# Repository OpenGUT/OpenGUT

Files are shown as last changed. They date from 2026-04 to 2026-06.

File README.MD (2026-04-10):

# OpenGut: An Open-Source Platform for Gut–Computer Interaction Research

OpenGut is an open-source platform designed to enable research at the intersection of human-computer interaction (HCI), physiology, and interoception. It provides a complete end-to-end system for sensing, analyzing, and interacting with gut activity through a wearable device, software interface, and extensible documentation.

## 🚀 Motivation
The gut plays a critical role in human physiology and cognition through the gut–brain axis. Despite growing interest in gut-based interaction, existing tools are fragmented, application-specific, and lack accessibility. OpenGut addresses this gap by providing a unified, reproducible, and extensible platform for researchers and developers.

## 🧩 System Overview
OpenGut consists of three main components:

### 1. Wearable Hardware
- Custom PCB based on Nordic nRF52840
- Dual-microphone setup (body-facing + ambient) for gut sound capture
- MicroSD storage for long-term recording
- Plug-and-play support for audio and haptic actuators
- Designed as a belt-worn system for continuous, real-world use

### 2. Software Interface (GUI)
- Real-time audio visualization (waveforms + spectrograms)
- Annotation tools for gut signal analysis
- Noise suppression and filtering pipelines
- Configurable recording and playback parameters

### 3. Documentation & Open Resources
- Hardware design files (PCB, enclosure)
- Firmware and software codebase
- Step-by-step setup and usage guides
- Modular design for easy customization and extension

## ⚙️ Supported Modes
OpenGut supports multiple modes of operation:

- **Logger Mode**: Long-term gut sound recording
- **Playback Mode**: Audio/haptic rendering of gut signals
- **Real-time Loopback Mode**: Live sensing and feedback

## 📊 Validation
OpenGut has been technically evaluated for:
- Signal quality (high correlation with medical-grade stethoscopes)
- Longitudinal gut activity tracking
- 24-hour recording capability with low power consumption

## 💡 Applications
- Interoception research and bodily awareness
- Mental and emotional state sensing
- Health monitoring and digestion studies
- Interactive media and immersive experiences
- Biofeedback and wearable computing

## 🔓 Open Source Vision
OpenGut aims to lower the barrier to entry in gut-computer interaction research by providing a fully open, reproducible, and extensible platform for the community.

## 🤝 Contributions
We welcome contributions from researchers, engineers, and designers interested in advancing gut-based interaction systems.

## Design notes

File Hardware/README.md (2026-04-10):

## PCB Design & Flashing Guide

<p align="center">
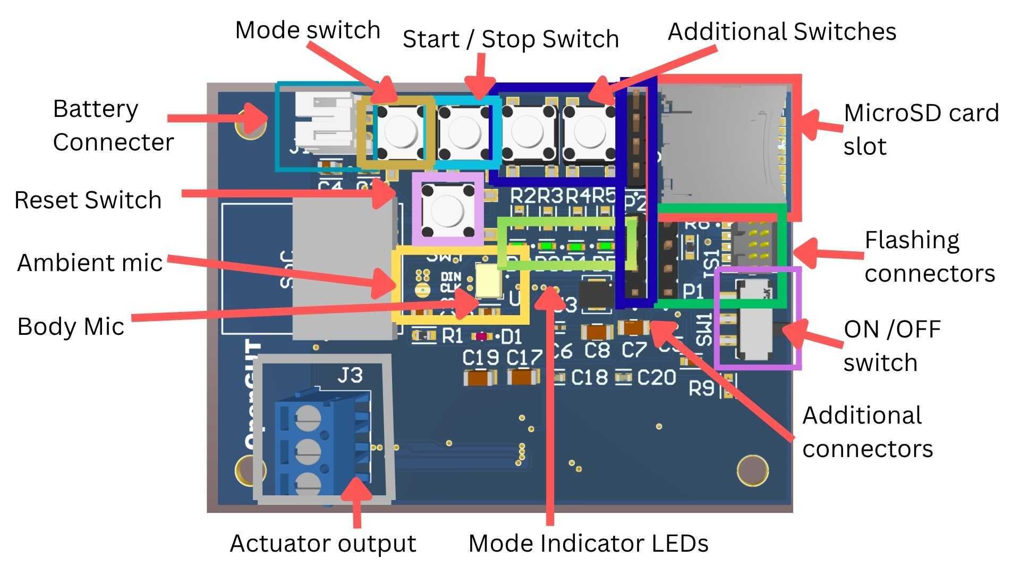
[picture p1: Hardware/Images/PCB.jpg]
  
</p>

The `Project_Output_OpenGUT.zip` file contains the Gerber files required for PCB manufacturing (e.g., via JLCPCB).

To modify the design, open the project file `OpenGUT.PrjPcb` in Altium Designer and make the necessary changes.

---

## Enclosure Design & Assembly Guide

### Overview
The enclosure consists of three 3D-printable components that house the electronics and provide a skin interface.

---

### Components

**Top Casing** – Protective upper shell  
<p align="center">
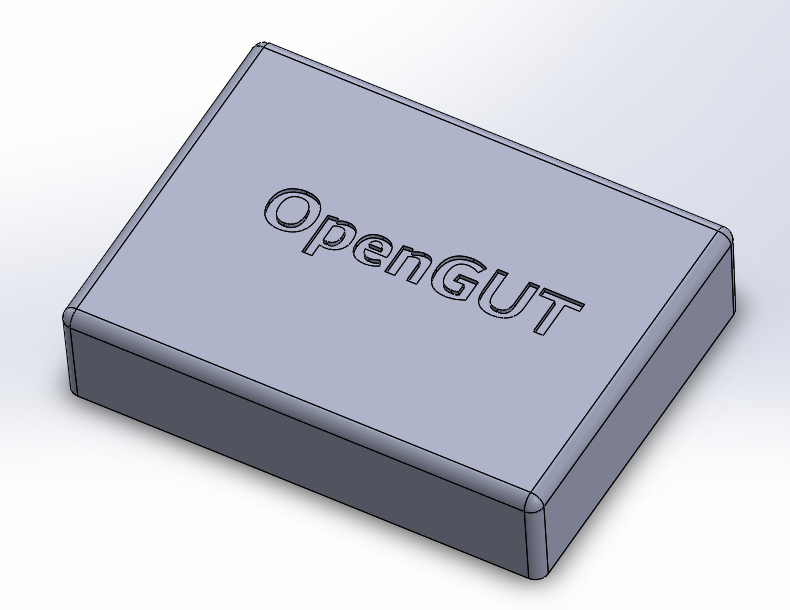
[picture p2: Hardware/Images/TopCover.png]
  
</p>

**Bottom Casing** – Structural base for internal components  
<p align="center">
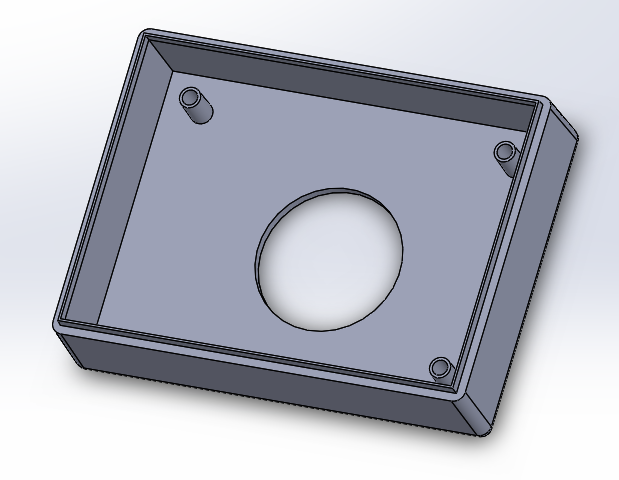
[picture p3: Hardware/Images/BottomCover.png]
  
</p>

**Conical Interface** – Skin-contact interface  
<p align="center">
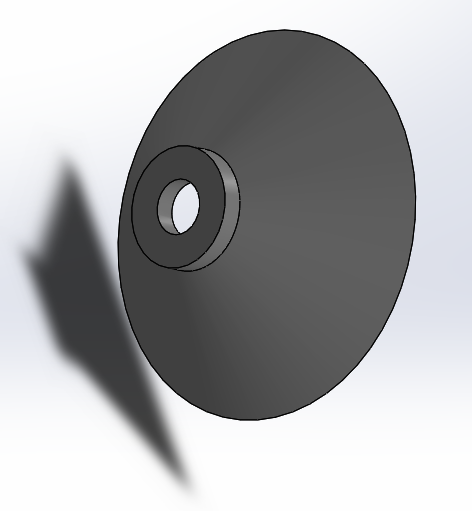
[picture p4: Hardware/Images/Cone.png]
  
</p>

---

## Assembly Instructions

### 1. Diaphragm Attachment
Attach a standard Littmann diaphragm directly to the cone.  
[Example Littmann diaphragm][littmann]

<p align="center">
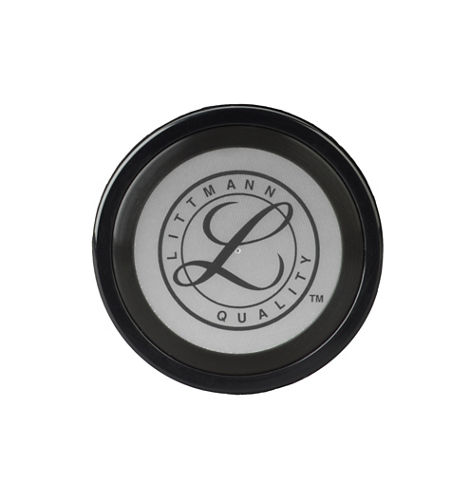
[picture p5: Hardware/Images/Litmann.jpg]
  
</p>

---

### 2. PCB & Casing Integration
- Screw the PCB into the mounting points on the bottom casing  
- Secure the cone to the bottom casing using hot glue  

<p align="center">
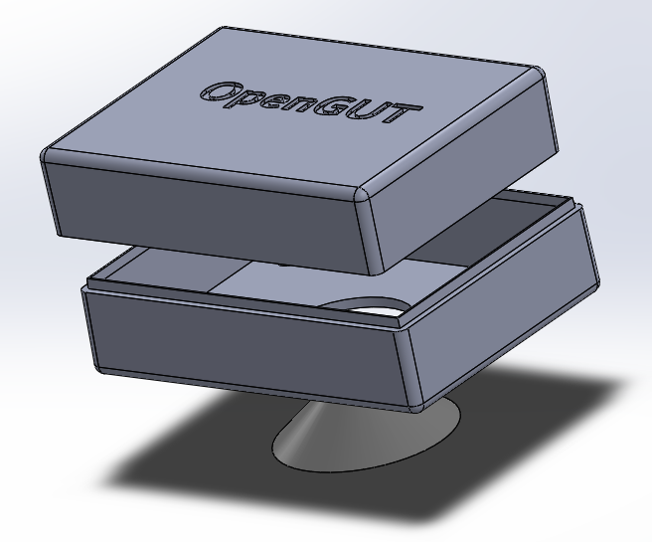
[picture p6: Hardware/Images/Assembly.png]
  
</p>

- Attach the top casing using the lip-and-groove mechanism  

---

### 3. Final Inspection
Ensure all components are securely fitted and properly aligned before use.

---

[littmann]: https://www.ebay.com/itm/366332360002

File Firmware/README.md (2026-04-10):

## Firmware Options

We provide two firmware versions depending on the researcher’s preferred workflow.

---

### 1. Firmware_UI_based_Selection

This firmware wraps all settings into the UI.

#### Setup & Flashing
- Set up the Zephyr / NCS environment  
  - Recommended: nRF Connect SDK on VS Code  
- Build the firmware  
- Flash using an nRF52840 DK  
  - Connect **Debug Out (DK)** → **Debug In (PCB)**  
- Flash the firmware onto the PCB  

Once flashed, the PCB is ready to use.

#### Usage
1. Insert the SD card into your laptop  
2. Using the provided UI, select:
   - Mode  
   - Sampling rate  
   - Duration  
   - File name  
3. Remove the SD card and insert it into the PCB  
4. Turn ON the PCB  

→ The selected mode will run automatically  

---

### 2. Firmware_Button_based_Selection

This firmware keeps primary settings (sampling rate, file name, etc.) in the UI,  
but allows mode control directly on the PCB using buttons.

#### Setup
- Same flashing process as above  
- Configure settings using the UI  

#### Usage
Once powered ON:

- **Button 1** → Select mode  
  - Current mode is indicated by LEDs:
    - **LED1** → Stereo recording  
    - **LED2** → Loopback  
    - **LED3** → Playback (File A)  
    - **LED4** → Playback (File B)  

- **Button 2** → Start / Stop  

---

### Why Use Button-Based Firmware?

This firmware allows researchers to:
- Quickly switch between modes  
- Avoid removing the SD card repeatedly  
- Test different configurations on the go

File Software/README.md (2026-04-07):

# OpenGUT Software - Device Configuration / Sound Processing / Annotation / File Export

A Qt6-based Python GUI application for OpenGUT project. Originally developed by OpenGUT engineering team.
- Preview and annotate audio files with interactive waveform and spectrogram visualization.

## Features

- **OpenGUT Device Configuration**: Simple GUI to configure an OpenGUT hardware and export settings in JSON format
- **Audio Visualization**: Interactive waveform and spectrogram displays for L/R channels using librosa and pyqtgraph
- **Audio Processing (Filtering)**: Audio processing - filtering input audio with 1) high-pass filter implemented with SciPy package, or 2) [AudioSep](https://github.com/ryohajika/AudioSep) ML-based engine using natural language
- **Annotation System**: Create, edit, and manage annotations with:
  - Annotation name
  - Start and stop time markers
  - Comments
  - Export annotated segments as WAVE files

## Installation

0. Install Python 3.12.13
```bash
# if you're on macOS, Homebrew and Pyenv are installed
pyenv install 3.12.13
# you may want to setup a virtualenv
```

1. Clone this project
```bash
git clone https://github.com/OpenGUT/OpenGUT
cd OpenGUT/Software
git submodule init && git submodule update
```

2. Install dependencies:
```bash
pip install -r requirements_pyenv3.12.13_venv.txt
```

3. Run the application:
```bash
python main.py
```

## Data Collection Usage

1. Prepare a microSD card for the OpenGUT PCB board
2. On the GUI, go to "Device Config" tab to export `config.json` file and download it to the microSD card
3. Load the microSD card on the PCB board and do data sampling

## Post Processing Usage

1. **Load Audio**: Use the file browser on the left to navigate and select a WAVE file
2. **Visualize**: The center pane shows the audio waveform or spectrogram (toggle with dropdown)
3. **Annotate**: Use the right pane to:
   - Enter annotation details (name, timing, comments)
   - Click "Add Annotation" to create new annotations
   - Select annotations from the list to edit or delete
   - Click "Export Segment" to save annotated sections as new WAVE files

#### Details are available from OpenGUT Official Documentation page: https://opengut.github.io

## Project Structure

```
.
├── app_settings.py                           # Application settings script
├── app_settings.json                         # JSON settings file that will be loaded/updated whenever we run this software **(if missing it will be generated automatically)**
├── const.py                                  # Constant values definition, mostly UI components labeling
├── main.py                                   # Application entry point
├── requirements_pyenv3.12.13_venv.txt        # Python dependencies including those libraries we need to run AudioSep
├── requirements.txt                          # Python dependencies
├── ui/
│   ├── __init__.py
│   ├── main_window.py      # Main window layout
│   ├── file_browser.py     # File tree widget
│   ├── audio_viewer.py     # Visualization widget
│   └── annotation_panel.py # Annotation controls
├── filters
│   ├── __init__.py
│   ├── template_filter.py  # Base filter script (user custom template)
│   ├── filter_loader.py    # Simple script that look up and load filters available
│   ├── scipy_highpass_filter.py              # Butterworth filter implemented with SciPy
│   ├── audiosep_filter.py  # Experimental filter with AudioSep library (No batch processing, experimental)
│   └── audiosep_filter2.py # Experimental filter with AudioSep library (batch processing enabled, experimental)
└── README.md               # This README
```

## Requirements
Refer `requirements_pyenv3.12.13_venv.txt` for the details.
This software has been built and tested on macOS26, Python 3.12.13. Also,

- PyQt6==6.6.1
- librosa==0.10.0
- pyqtgraph==0.13.7
- numpy==1.24.3
- scipy==1.11.4
- soundfile==0.12.1

For the AudioSep filtering, we also used

- tokenizers>=0.14.0,<0.15
- transformers==4.34.0
- torch==2.10.0
- gradio==3.47.1

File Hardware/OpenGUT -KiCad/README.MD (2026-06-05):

# OpenGUT – KiCad PCB Design

This repository contains KiCad design files for the **OpenGUT** hardware platform.  
It extends the original OpenGUT repository by providing open-source PCB layouts and schematics created in KiCad.

---

## ✨ Contribution Highlights
- **KiCad PCB Design Files**: Complete board design using KiCad, ensuring accessibility and reproducibility in an open-source EDA toolchain.
- **IMU Integration**: Added an Inertial Measurement Unit (IMU) to support **noise cancellation** and enhanced sensing capabilities.
- **Open-Source Alignment**: Since OpenGUT is an open-source platform, developing its PCB in KiCad strengthens transparency, collaboration, and community-driven improvements.

---

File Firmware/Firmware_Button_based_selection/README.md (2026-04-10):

# Firmware UI Based Selection

- Use this firmware if you want to select modes using the buttons on the PCB. 

## Project Structure

- `src/` - Application source files
- `boards/` - Board overlay files
- `prj.conf` - Zephyr project configuration
- `CMakeLists.txt` - Build configuration

## Quick Start

1. Configure your Zephyr/NCS environment.
2. Build the project from the workspace root:
   ```bash
   west build -b nrf54l15dk_nrf54l15_cpuapp
   ```
3. Flash to the board:
   ```bash
   west flash
   ```

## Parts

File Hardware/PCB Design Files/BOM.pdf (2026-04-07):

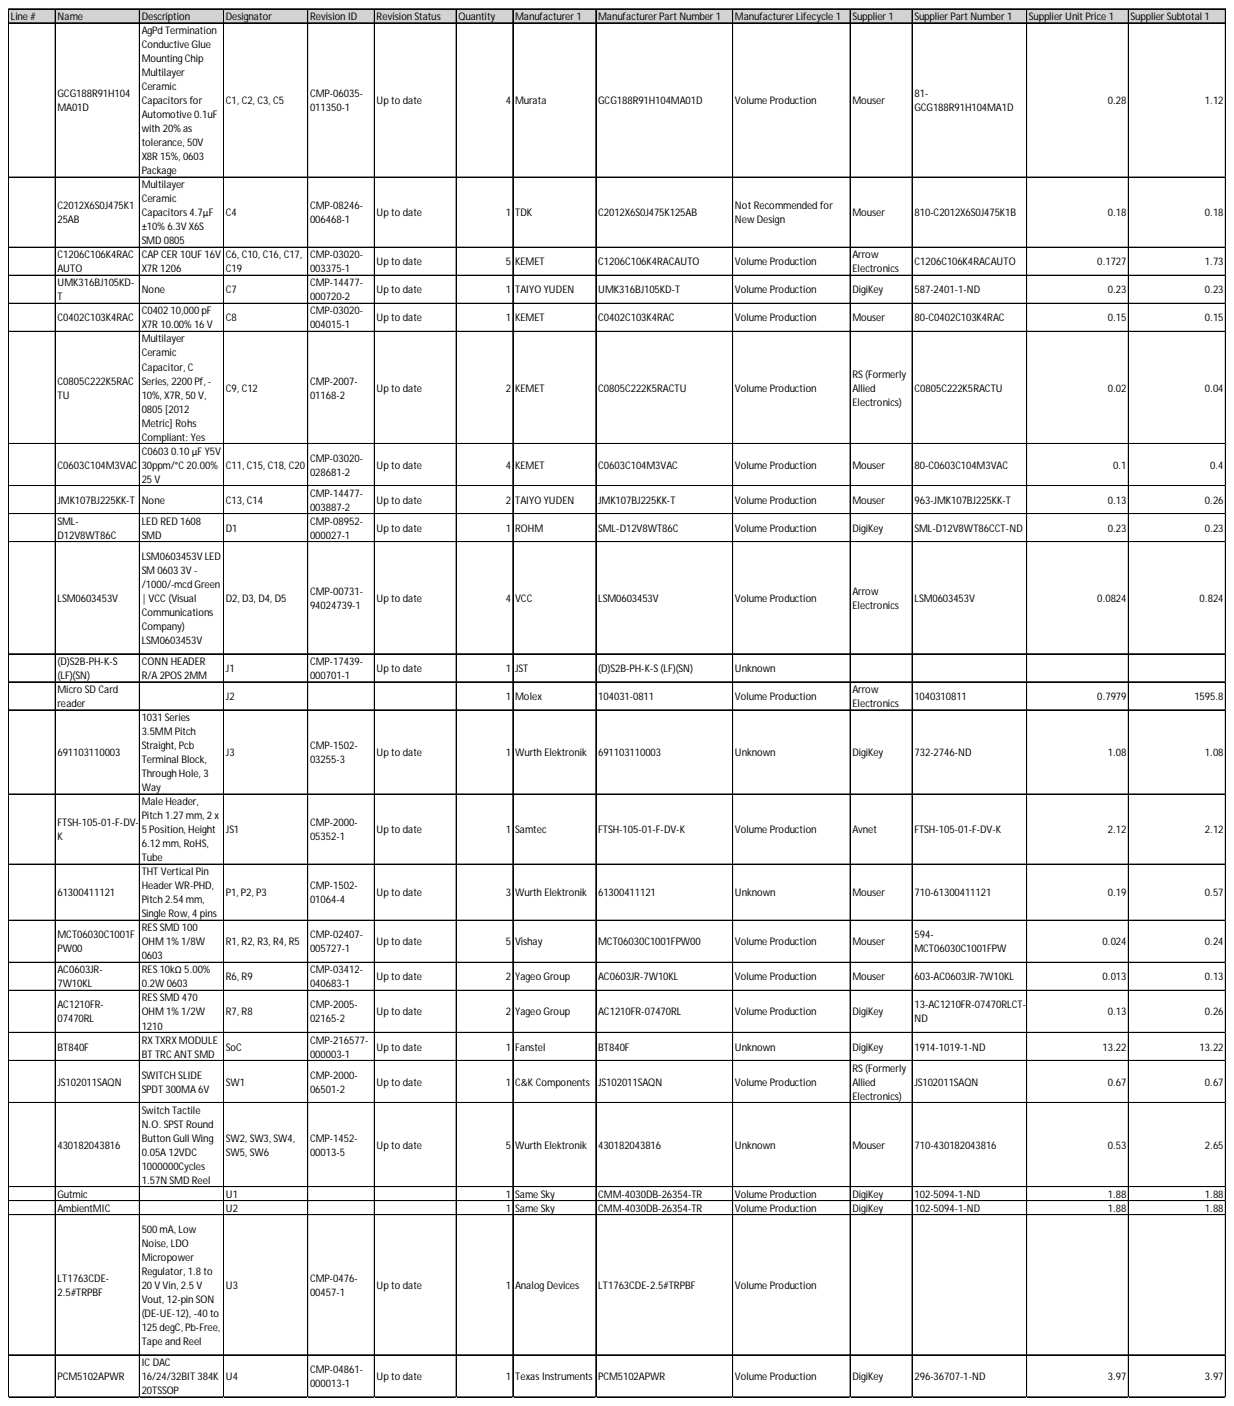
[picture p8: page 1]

Line # | Name | Description | Designator | Revision ID | Revision Status | Quantity | Manufacturer 1 | Manufacturer Part Number 1 | Manufacturer Lifecycle 1 | Supplier 1 | Supplier Part Number 1 | Supplier Unit Price 1 | Supplier Subtotal 1

GCG188R91H104 MA01D | AgPd Termination Conductive Glue Mounting Chip Multilayer Ceramic Capacitors for Automotive 0.1uF with 20% as tolerance, 50V X8R 15%, 0603 Package | C1, C2, C3, C5 | CMP-06035-011350-1 | Up to date | 4 Murata | | GCG188R91H104MA01D | Volume Production | Mouser | 81-GCG188R91H104MA1D | 0.28 | 1.12

C2012X6S0J475K1 25AB | Multilayer Ceramic Capacitors 4.7μF ±10% 6.3V X6S SMD 0805 | C4 | CMP-08246-006468-1 | Up to date | 1 | TDK | C2012X6S0J475K125AB | Not Recommended for New Design | Mouser | 810-C2012X6S0J475K1B | 0.18 | 0.18

C1206C106K4RAC AUTO | CAP CER 10UF 16V X7R 1206 | C6, C10, C16, C17, C19 | CMP-03020-003375-1 | Up to date | 5 | KEMET | C1206C106K4RACAUTO | Volume Production | Arrow Electronics | C1206C106K4RACAUTO | 0.1727 | 1.73

UMK316BJ105KD-T | None | C7 | CMP-14477-000720-2 | Up to date | 1 | TAIYO YUDEN | UMK316BJ105KD-T | Volume Production | DigiKey | 587-2401-1-ND | 0.23 | 0.23

C0402C103K4RAC | C0402 10,000 pF X7R 10.00% 16 V | C8 | CMP-03020-004015-1 | Up to date | 1 | KEMET | C0402C103K4RAC | Volume Production | Mouser | 80-C0402C103K4RAC | 0.15 | 0.15

C0805C222K5RAC TU | Multilayer Ceramic Capacitor, C Series, 2200 Pf, -10%, X7R, 50 V, 0805 [2012 Metric] Rohs Compliant: Yes | C9, C12 | CMP-2007-01168-2 | Up to date | 2 | KEMET | C0805C222K5RACTU | Volume Production | RS (Formerly Allied Electronics) | C0805C222K5RACTU | 0.02 | 0.04

C0603C104M3VAC | C0603 0.10 μF Y5V 30ppm/°C 20.00% 25 V | C11, C15, C18, C20 | CMP-03020-028681-2 | Up to date | 4 KEMET | | C0603C104M3VAC | Volume Production | Mouser | 80-C0603C104M3VAC | 0.1 | 0.4

JMK107BJ225KK-T | None | C13, C14 | CMP-14477-003887-2 | Up to date | 2 | TAIYO YUDEN | JMK107BJ225KK-T | Volume Production | Mouser | 963-JMK107BJ225KK-T | 0.13 | 0.26

SML-D12V8WT86C | LED RED 1608 SMD | D1 | CMP-08952-000027-1 | Up to date | 1 | ROHM | SML-D12V8WT86C | Volume Production | DigiKey | SML-D12V8WT86CCT-ND | 0.23 | 0.23

LSM0603453V | LSM0603453V LED SM 0603 3V -/1000/-mcd Green | VCC (Visual Communications Company) LSM0603453V | D2, D3, D4, D5 | CMP-00731-94024739-1 | Up to date | 4 VCC | | LSM0603453V | Volume Production | Arrow Electronics | LSM0603453V | 0.0824 | 0.824

(D)S2B-PH-K-S (LF)(SN) | CONN HEADER R/A 2POS 2MM | J1 | CMP-17439-000701-1 | Up to date | 1 | JST | (D)S2B-PH-K-S (LF)(SN) | Unknown

Micro SD Card reader | | J2 | | | 1 | Molex | 104031-0811 | Volume Production | Arrow Electronics | 1040310811 | 0.7979 | 1595.8

691103110003 | 1031 Series 3.5MM Pitch Straight, Pcb Terminal Block, Through Hole, 3 Way | J3 | CMP-1502-03255-3 | Up to date | 1 | Wurth Elektronik | 691103110003 | Unknown | DigiKey | 732-2746-ND | 1.08 | 1.08

FTSH-105-01-F-DV-K | Male Header, Pitch 1.27 mm, 2 x 5 Position, Height 6.12 mm, RoHS, Tube | JS1 | CMP-2000-05352-1 | Up to date | 1 | Samtec | FTSH-105-01-F-DV-K | Volume Production | Avnet | FTSH-105-01-F-DV-K | 2.12 | 2.12

61300411121 | THT Vertical Pin Header WR-PHD, Pitch 2.54 mm, Single Row, 4 pins | P1, P2, P3 | CMP-1502-01064-4 | Up to date | 3 | Wurth Elektronik | 61300411121 | Unknown | Mouser | 710-61300411121 | 0.19 | 0.57

MCT06030C1001F PW00 | RES SMD 100 OHM 1% 1/8W 0603 | R1, R2, R3, R4, R5 | CMP-02407-005727-1 | Up to date | 5 | Vishay | MCT06030C1001FPW00 | Volume Production | Mouser | 594-MCT06030C1001FPW | 0.024 | 0.24

AC0603JR-7W10KL | RES 10kΩ 5.00% 0.2W 0603 | R6, R9 | CMP-03412-040683-1 | Up to date | 2 | Yageo Group | AC0603JR-7W10KL | Volume Production | Mouser | 603-AC0603JR-7W10KL | 0.013 | 0.13

AC1210FR-07470RL | RES SMD 470 OHM 1% 1/2W 1210 | R7, R8 | CMP-2005-02165-2 | Up to date | 2 | Yageo Group | AC1210FR-07470RL | Volume Production | DigiKey | 13-AC1210FR-07470RLCT-ND | 0.13 | 0.26

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

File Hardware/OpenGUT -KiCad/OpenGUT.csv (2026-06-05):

Reference | Qty | Value | DNP | Exclude from BOM | Exclude from Board | Footprint | Datasheet
C1,C2,C9,C10,C12,C14,C15,C16 | 8 | 0.1 uF |  |  |  | Capacitor_SMD:C_0603_1608Metric_Pad1.08x0.95mm_HandSolder | ~
C3,C8,C11,C13,C24,C27 | 6 | 10 uF |  |  |  | Capacitor_SMD:C_0603_1608Metric_Pad1.08x0.95mm_HandSolder | ~
C4,C6 | 2 | 2.2 nF |  |  |  | Capacitor_SMD:C_0603_1608Metric_Pad1.08x0.95mm_HandSolder | ~
C5,C7 | 2 | 2.2 uF |  |  |  | Capacitor_SMD:C_0603_1608Metric_Pad1.08x0.95mm_HandSolder | ~
C17,C19 | 2 | 100 nF |  |  |  | Capacitor_SMD:C_0603_1608Metric_Pad1.08x0.95mm_HandSolder | ~
C18 | 1 | 220 nF |  |  |  | Capacitor_SMD:C_0603_1608Metric_Pad1.08x0.95mm_HandSolder | ~
C20,C23,C26 | 3 | 1 uF |  |  |  | Capacitor_SMD:C_0603_1608Metric_Pad1.08x0.95mm_HandSolder | ~
C21 | 1 | 4.7 uF |  |  |  | Capacitor_SMD:C_0603_1608Metric_Pad1.08x0.95mm_HandSolder | ~
C22,C25 | 2 | 0.01 uF |  |  |  | Capacitor_SMD:C_0603_1608Metric_Pad1.08x0.95mm_HandSolder | ~
D1,D2,D3,D4 | 4 | LED |  |  |  | LED_SMD:LED_0603_1608Metric_Pad1.05x0.95mm_HandSolder | ~
D5 | 1 | P |  |  |  | LED_SMD:LED_0603_1608Metric_Pad1.05x0.95mm_HandSolder | ~
J1 | 1 | SJ-3524-SMT |  |  |  | SJ-3524-SMT:CUI_SJ-3524-SMT | 3.5mm Audio Jack
J2 | 1 | MicroSD |  |  |  | 104031-0811:MOLEX_104031-0811
J3 | 1 | DAC |  |  |  | Package_SO:TSSOP-20_4.4x6.5mm_P0.65mm | https://www.ti.com/lit/ds/symlink/pcm5102a.pdf
J4 | 1 | DEBUG OUT |  |  |  | FTSH-105-01-X-DV-K:SAMTEC_FTSH-105-01-X-DV-K
J5 | 1 | S2B-PH-K-S_LF__SN_ |  |  |  | S2B-PH-K-S_LF__SN_:JST_S2B-PH-K-S_LF__SN_
MK1 | 1 | BODY MIC |  |  |  | Sensor_Audio:Knowles_LGA-5_3.5x2.65mm | https://www.knowles.com/docs/default-source/model-downloads/sph0641lu4h-1-revb.pdf
MK2 | 1 | AMBIENT MIC |  |  |  | Sensor_Audio:Knowles_LGA-5_3.5x2.65mm | https://www.knowles.com/docs/default-source/model-downloads/sph0641lu4h-1-revb.pdf
R1,R3,R5,R6,R11 | 5 | R |  |  |  | Resistor_SMD:R_0603_1608Metric_Pad0.98x0.95mm_HandSolder | ~
R2,R4 | 2 | 470 |  |  |  | Resistor_SMD:R_0603_1608Metric_Pad0.98x0.95mm_HandSolder | ~
R7 | 1 | 10 k |  |  |  | Resistor_SMD:R_0603_1608Metric_Pad0.98x0.95mm_HandSolder | ~
R8,R10 | 2 | 4.7 k |  |  |  | Resistor_SMD:R_0603_1608Metric_Pad0.98x0.95mm_HandSolder | ~
R9 | 1 | 10k |  |  |  | Resistor_SMD:R_0603_1608Metric_Pad0.98x0.95mm_HandSolder | ~
S1 | 1 | START/STOP |  |  |  | 430182043816:430182043816
S2 | 1 | MODE |  |  |  | 430182043816:430182043816
S3 | 1 | RESET |  |  |  | 430182043816:430182043816
SW1 | 1 | OFF | ON |  |  |  | JS102011SAQN:SW_JS102011SAQN
U1 | 1 | BT840F |  |  |  | BT840F:XCVR_BT840F
U2 | 1 | IMU |  |  |  | BHI360:XDCR_BHI360
U3 | 1 | 1V8 |  |  |  | LT1763CDE-1.8_PBF:DFN-12_DE
U4 | 1 | 3V3 |  |  |  | LT1763CDE-3.3_PBF:DFN-12_DE

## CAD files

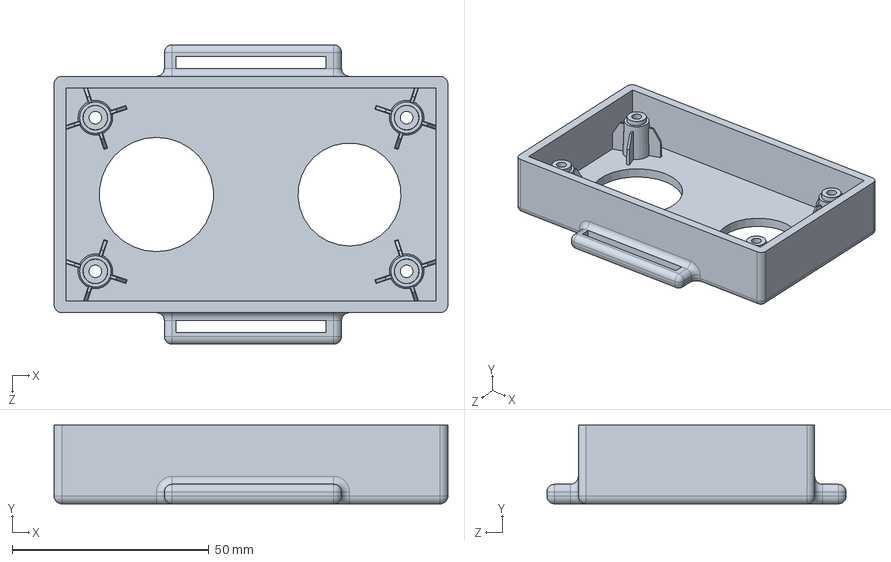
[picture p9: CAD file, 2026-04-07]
Hardware/Enclosure Design Files/Bottom Cover.SLDPRT
100.0 x 20.0 x 76.0 mm

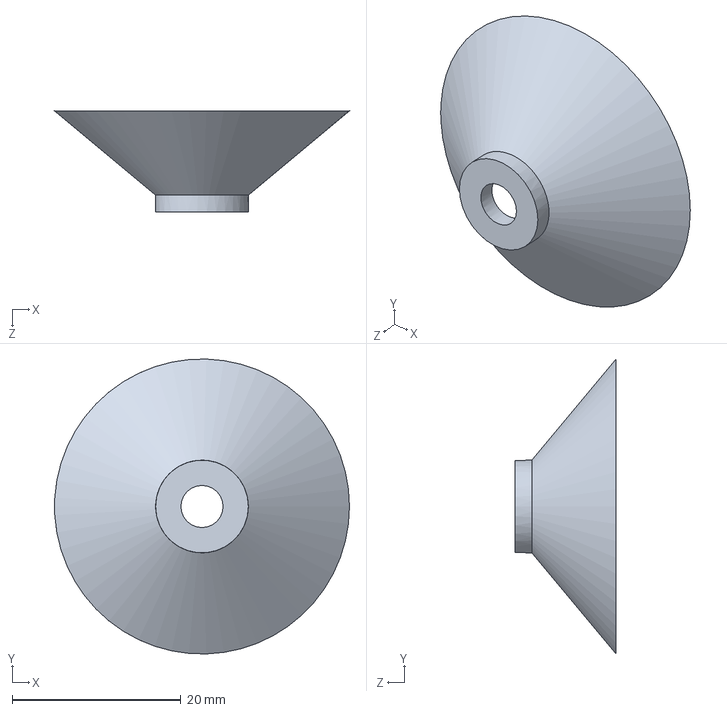
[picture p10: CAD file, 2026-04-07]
Hardware/Enclosure Design Files/Cone.SLDPRT
35.0 x 35.0 x 12.0 mm

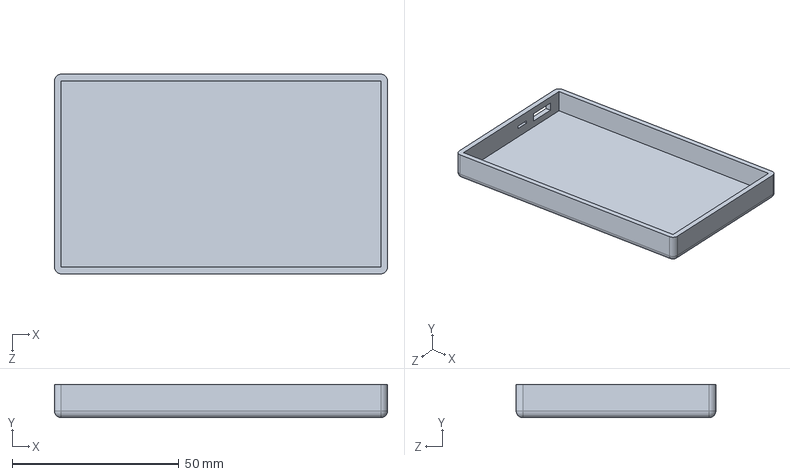
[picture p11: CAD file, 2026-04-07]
Hardware/Enclosure Design Files/Top Cover.SLDPRT
100.0 x 10.0 x 60.0 mm

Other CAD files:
Hardware/Enclosure Design Files/Cone.STL
Hardware/Enclosure Design Files/bottom cover.STL
Hardware/Enclosure Design Files/top cover.STL

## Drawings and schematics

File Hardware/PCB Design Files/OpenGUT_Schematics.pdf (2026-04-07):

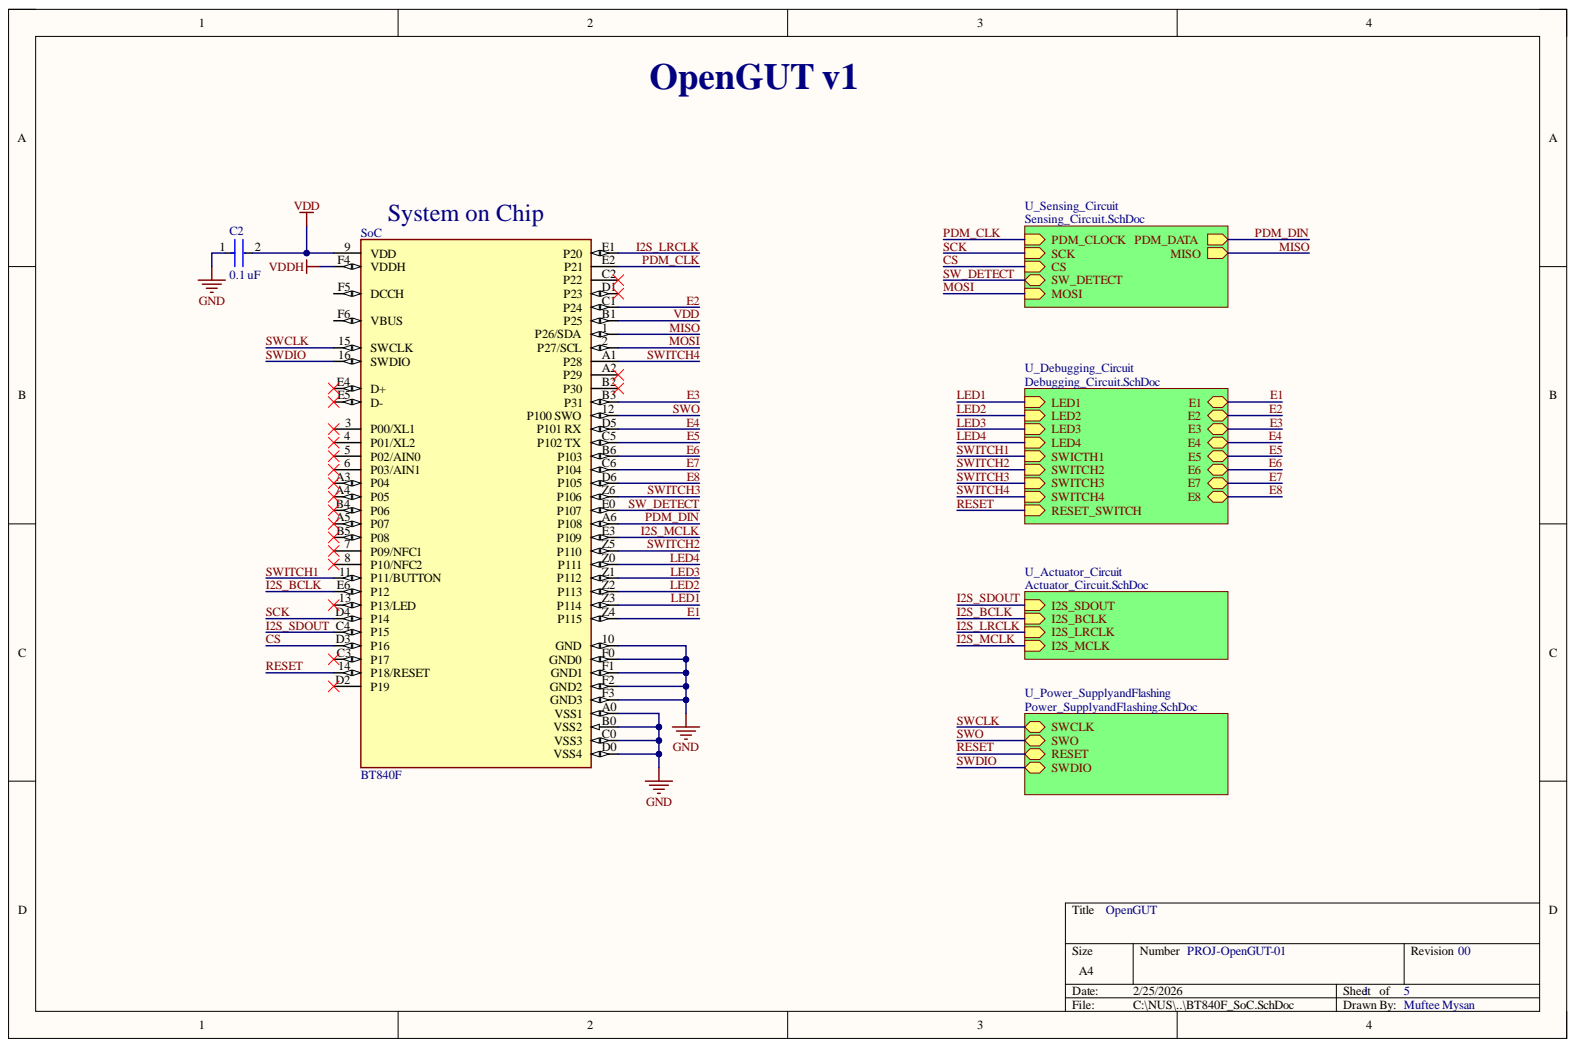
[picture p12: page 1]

F 0
F 1 | U_Powe r_SupplyandF l a s hin g Powe r_SupplyandFlashi n g . S c hD o c
F 2
F 3

Siz e A4 | Numb e r P ROJ-Ope n GU T-0 1 | 5 R evisio n 00 1

Da te : 2/25/202 6 | She et of
File : C:\NUS\. .\BT840F_SoC . S c hD o c | Dr awn B y : Mufte e Mys an

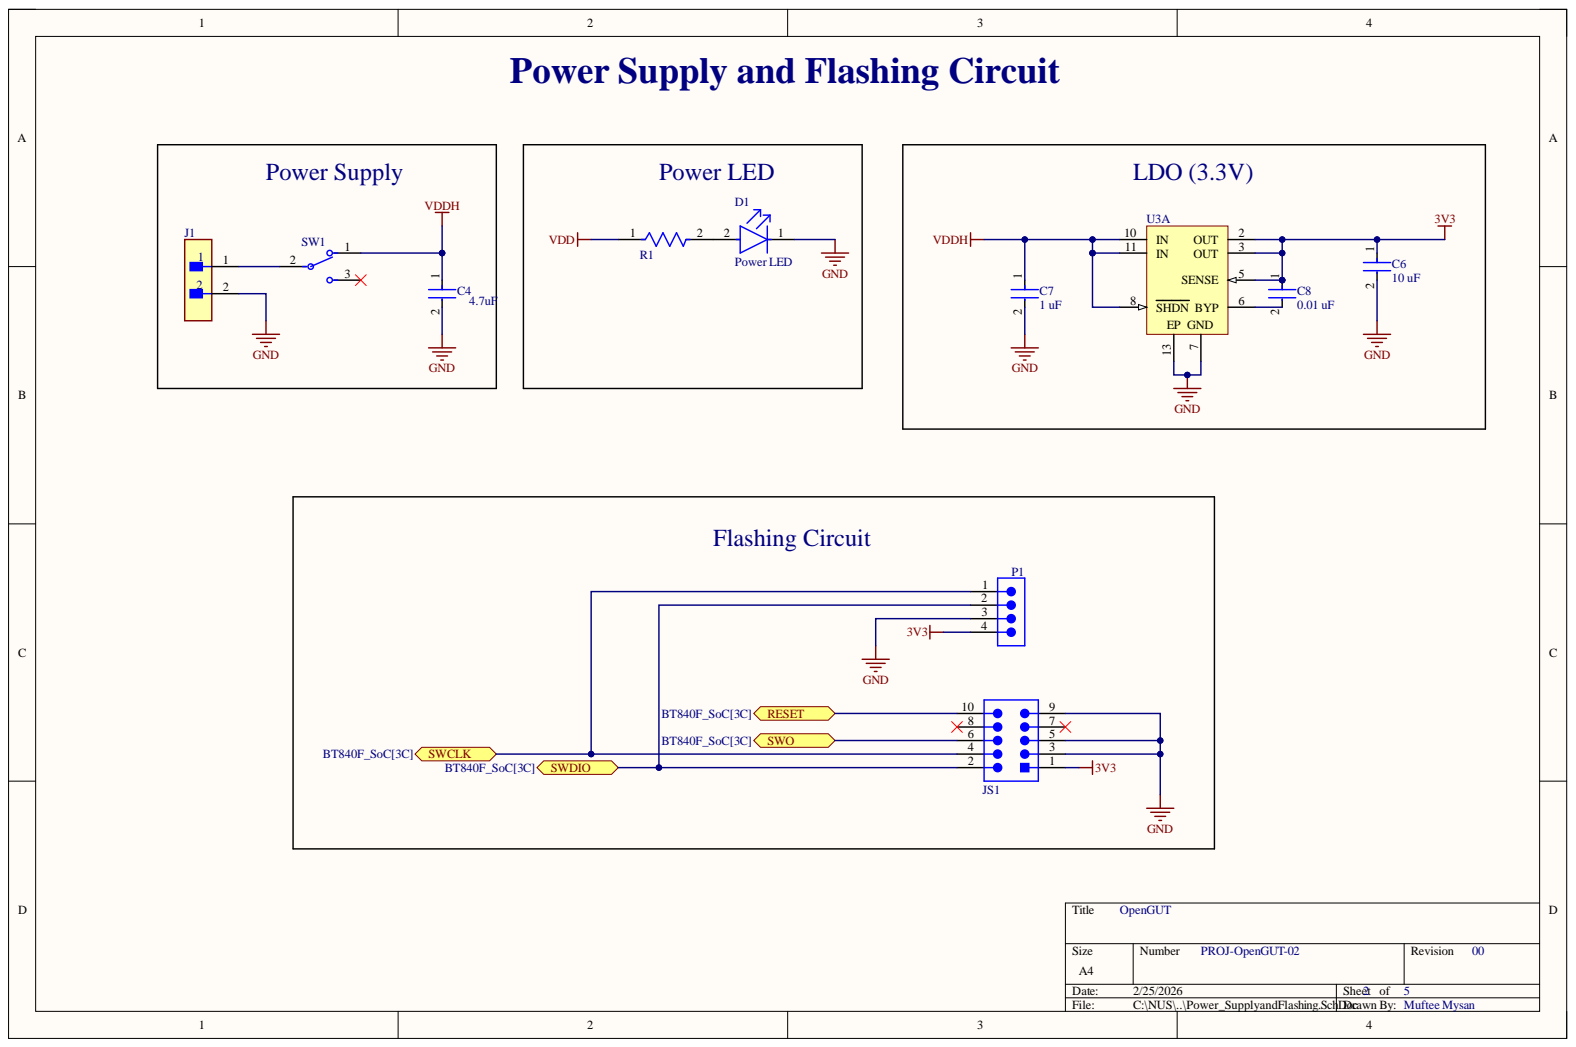
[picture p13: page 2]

Power Supply and Flashing Circuit

Size A4 | Number PROJ-OpenGUT-02 | Revision 00

Date: 2/25/2026 | Sheet of 2 5
File: C:\NUS\..\Power_SupplyandFlashing.SchDDrocawn By: | Muftee Mysan

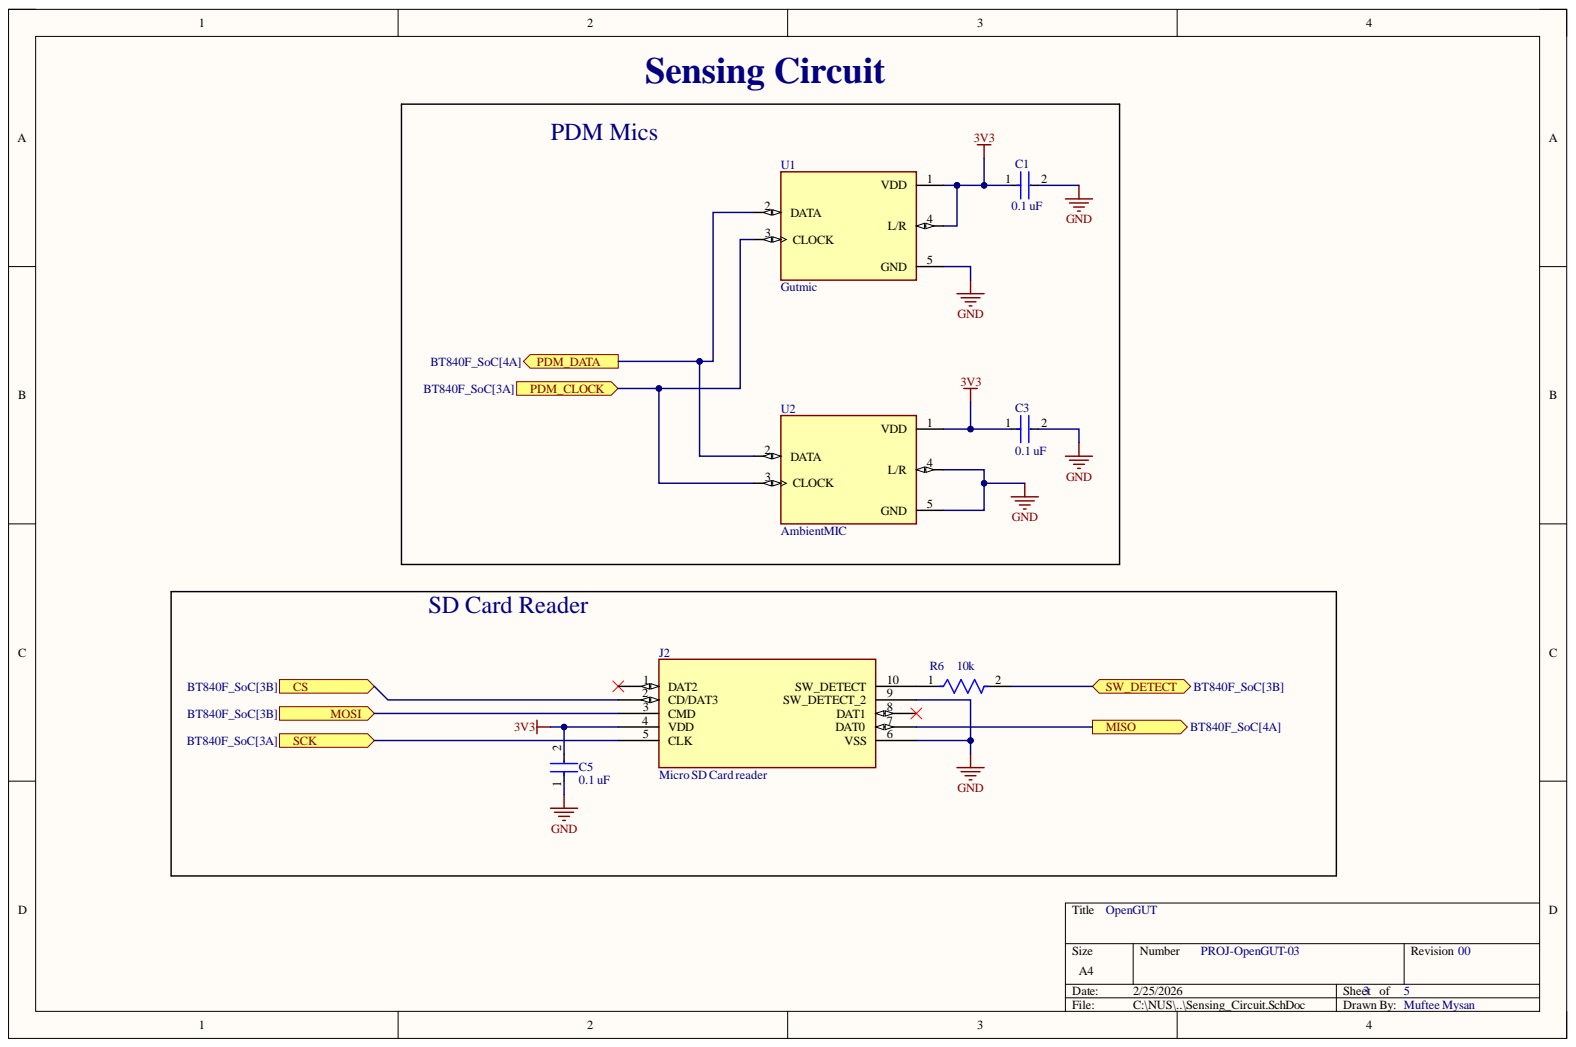
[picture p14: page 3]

Micro SD Card reader

Size A4 | Number PROJ-OpenGUT-03 | Revision 00

Date: 2/25/2026 | Sheet of 3 5
File: C:\NUS\..\Sensing_Circuit.SchDoc | Drawn By: Muftee Mysan

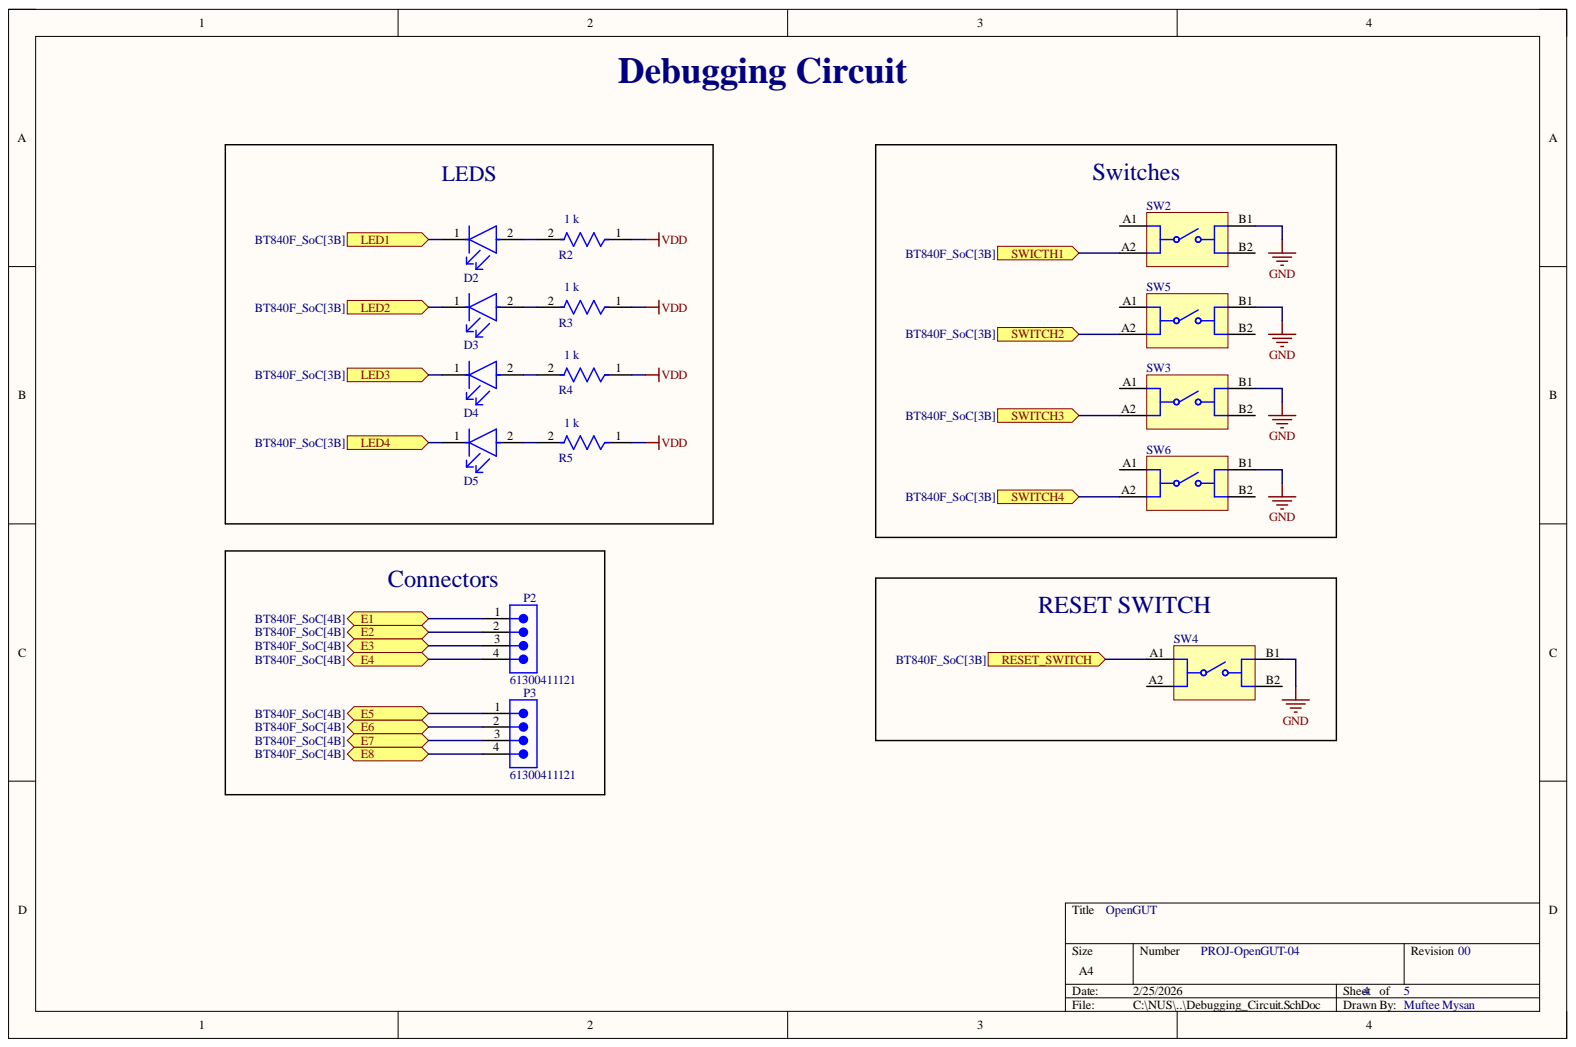
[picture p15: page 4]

Size A4 | Number PROJ-OpenGUT-04 | Revision 00

Date: 2/25/2026 | Sheet of 4 5
File: C:\NUS\..\Debugging_Circuit.SchDoc | Drawn By: Muftee Mysan

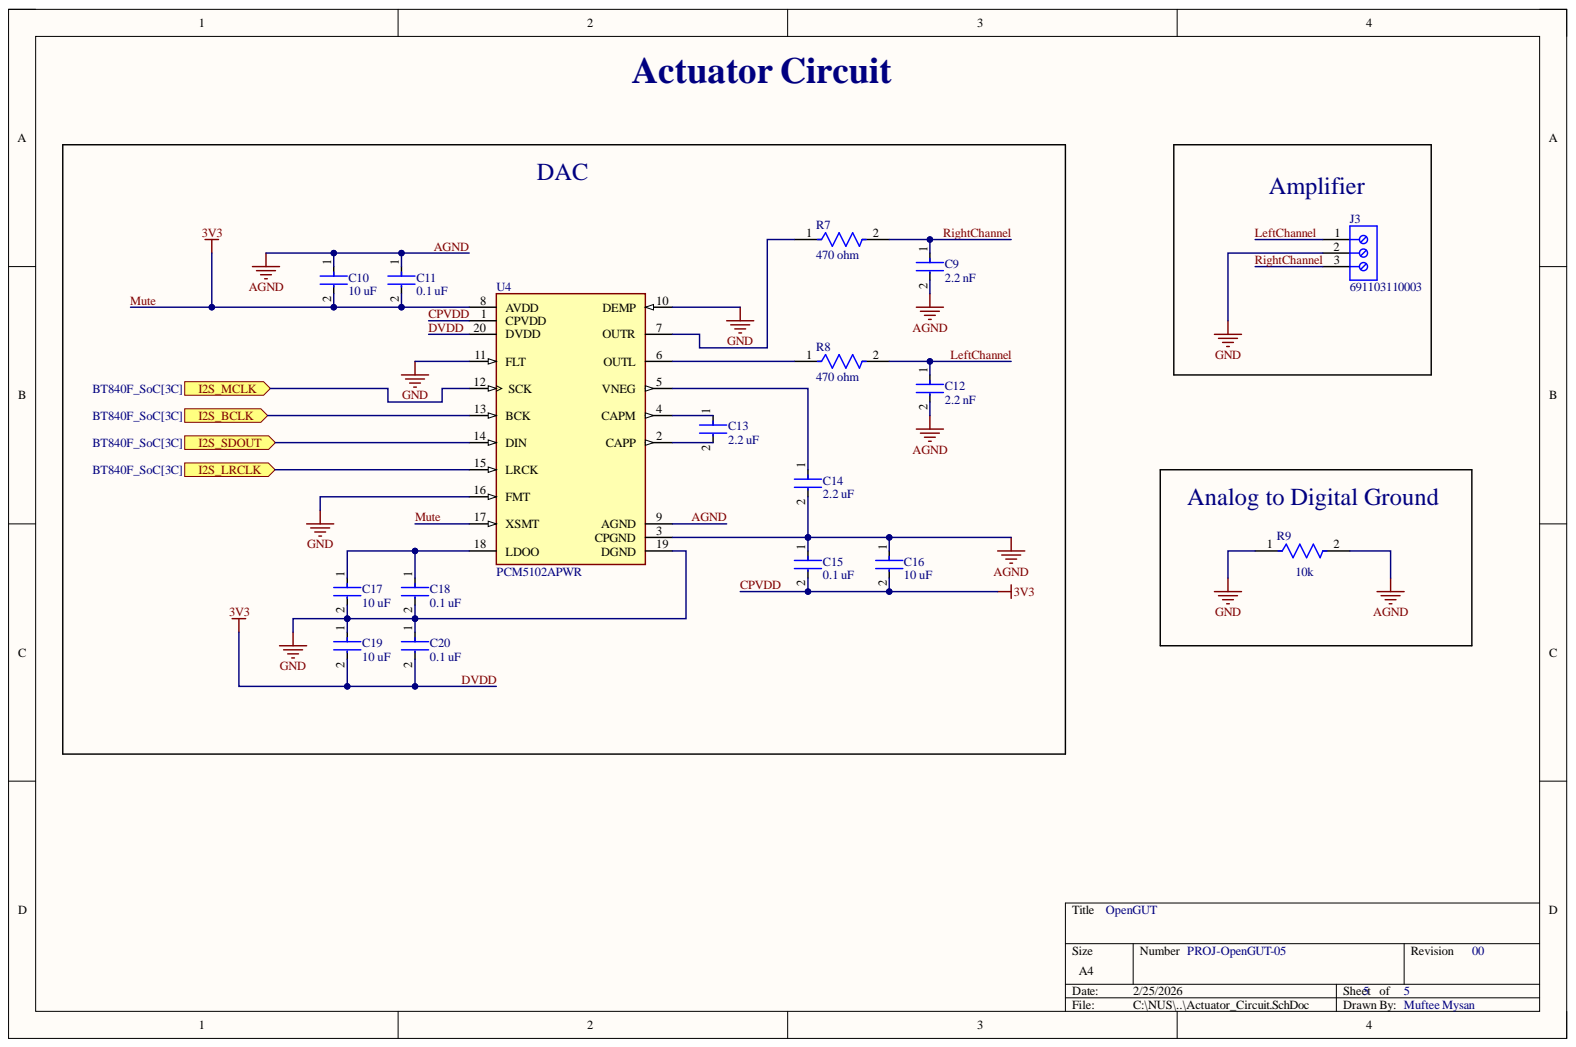
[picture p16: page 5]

Siz e A4 | Numb e r P ROJ-Ope n GU T-0 5 | 5 R evisio n 00 5

Da te : 2/25/202 6 | She et of
File : C:\NUS\. .\Actuator_Cir c uit . S c hD o c | Dr awn B y : Mufte e Mys an

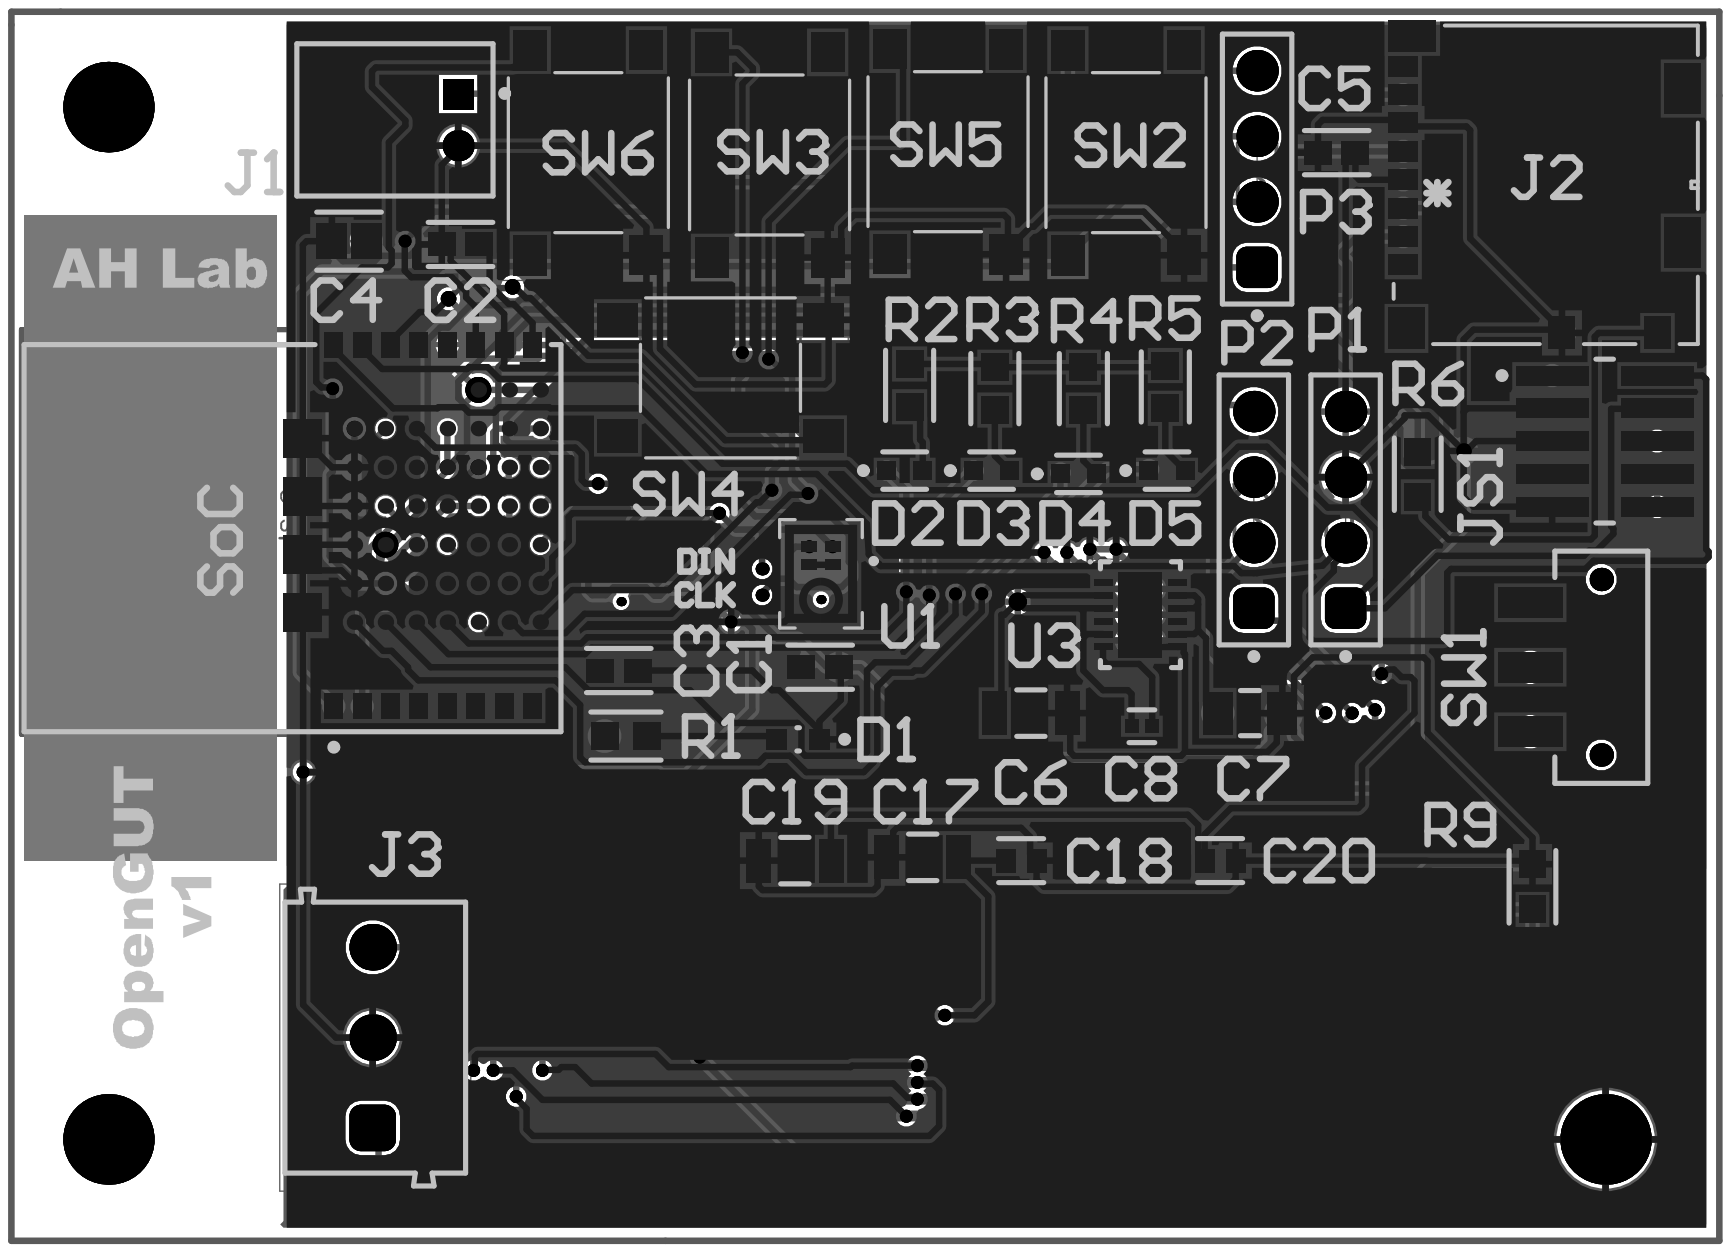
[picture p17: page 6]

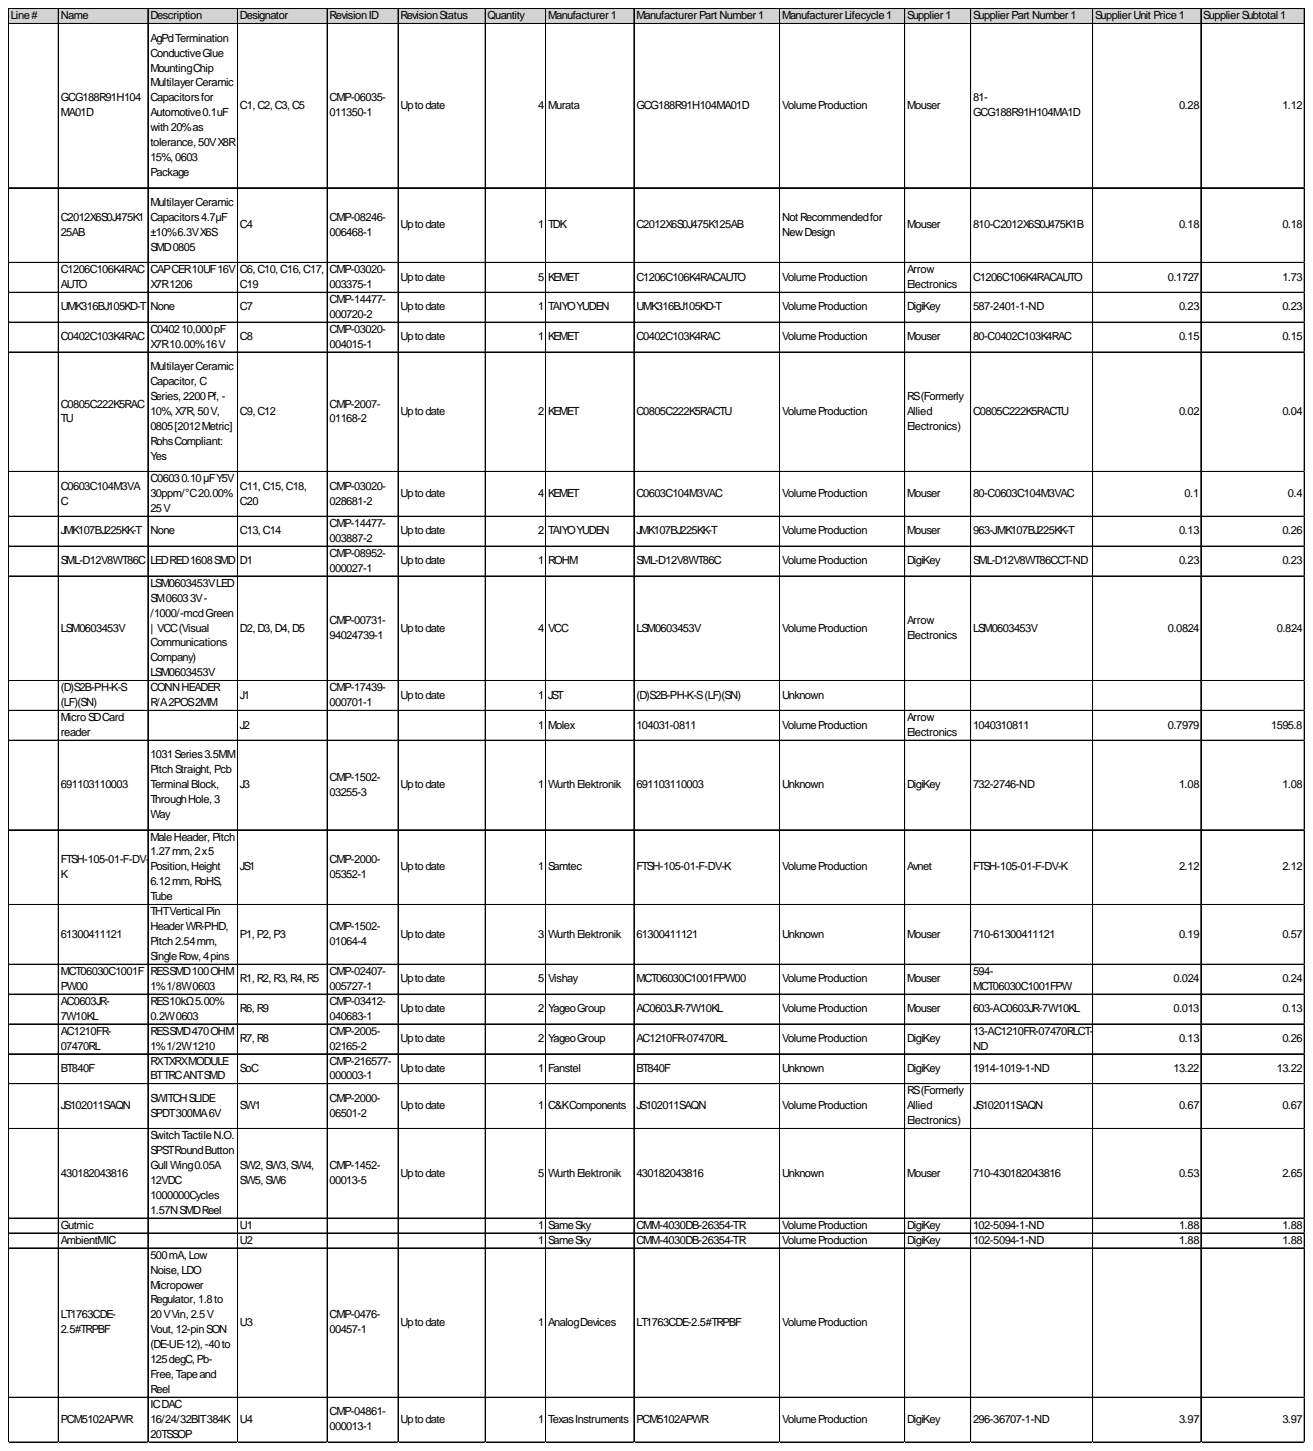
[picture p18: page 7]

Line# | Name | Description | Designator | RevisionID | RevisionStatus | Quantity | Manufacturer 1 | Manufacturer Part Number 1 | Manufacturer Lifecycle 1 | Supplier 1 | Supplier Part Number 1 | Supplier Unit Price 1 | Supplier Subtotal 1

GCG188R91H104 MA01D | AgPdTermination ConductiveGlue MountingChip Multilayer Ceramic Capacitors for Automotive0.1uF with 20%as tolerance, 50VX8R 15%, 0603 Package | C1, C2, C3, C5 | CMP-06035-011350-1 | Uptodate | 4 | Murata | GCG188R91H104MA01D | VolumeProduction | Mouser | 81-GCG188R91H104MA1D | 0.28 | 1.12

C2012X6S0J475K1 25AB | Multilayer Ceramic Capacitors 4.7μF ±10%6.3VX6S SMD0805 | C4 | CMP-08246-006468-1 | Uptodate | 1 | TDK | C2012X6S0J475K125AB | Not Recommendedfor NewDesign | Mouser | 810-C2012X6S0J475K1B | 0.18 | 0.18

C1206C106K4RAC AUTO | CAPCER10UF16V X7R1206 | C6, C10, C16, C17, C19 | CMP-03020-003375-1 | Uptodate | 5 | KEMET | C1206C106K4RACAUTO | VolumeProduction | Arrow Electronics | C1206C106K4RACAUTO | 0.1727 | 1.73

UMK316BJ105KD-T | None | C7 | CMP-14477-000720-2 | Uptodate | 1 | TAIYOYUDEN | UMK316BJ105KD-T | VolumeProduction | DigiKey | 587-2401-1-ND | 0.23 | 0.23

C0402C103K4RAC | C040210,000pF X7R10.00%16V | C8 | CMP-03020-004015-1 | Uptodate | 1 | KEMET | C0402C103K4RAC | VolumeProduction | Mouser | 80-C0402C103K4RAC | 0.15 | 0.15

C0805C222K5RAC TU | Multilayer Ceramic Capacitor, C Series, 2200Pf, -10%, X7R, 50V, 0805[2012Metric] RohsCompliant: Yes | C9, C12 | CMP-2007-01168-2 | Uptodate | 2 | KEMET | C0805C222K5RACTU | VolumeProduction | RS(Formerly Allied Electronics) | C0805C222K5RACTU | 0.02 | 0.04

C0603C104M3VA C | C06030.10μFY5V 30ppm/°C20.00% 25V | C11, C15, C18, C20 | CMP-03020-028681-2 | Uptodate | 4 | KEMET | C0603C104M3VAC | VolumeProduction | Mouser | 80-C0603C104M3VAC | 0.1 | 0.4

JMK107BJ225KK-T | None | C13, C14 | CMP-14477-003887-2 | Uptodate | 2 | TAIYOYUDEN | JMK107BJ225KK-T | VolumeProduction | Mouser | 963-JMK107BJ225KK-T | 0.13 | 0.26

SML-D12V8WT86C | LEDRED1608SMD | D1 | CMP-08952-000027-1 | Uptodate | 1 | ROHM | SML-D12V8WT86C | VolumeProduction | DigiKey | SML-D12V8WT86CCT-ND | 0.23 | 0.23

LSM0603453V | LSM0603453VLED SM06033V-/1000/-mcdGreen | VCC(Visual Communications Company) LSM0603453V | D2, D3, D4, D5 | CMP-00731-94024739-1 | Uptodate | 4 | VCC | LSM0603453V | VolumeProduction | Arrow Electronics | LSM0603453V | 0.0824 | 0.824

(D)S2B-PH-K-S (LF)(SN) | CONNHEADER R/A2POS2MM | J1 | CMP-17439-000701-1 | Uptodate | 1 | JST | (D)S2B-PH-K-S(LF)(SN) | Unknown

MicroSDCard reader | | J2 | | | 1 | Molex | 104031-0811 | VolumeProduction | Arrow Electronics | 1040310811 | 0.7979 | 1595.8

691103110003 | 1031Series3.5MM PitchStraight, Pcb Terminal Block, ThroughHole, 3 Way | J3 | CMP-1502-03255-3 | Uptodate | 1 | WurthElektronik | 691103110003 | Unknown | DigiKey | 732-2746-ND | 1.08 | 1.08

FTSH-105-01-F-DV-K | MaleHeader, Pitch 1.27mm, 2x5 Position, Height 6.12mm, RoHS, Tube | JS1 | CMP-2000-05352-1 | Uptodate | 1 | Samtec | FTSH-105-01-F-DV-K | VolumeProduction | Avnet | FTSH-105-01-F-DV-K | 2.12 | 2.12

61300411121 | THTVertical Pin Header WR-PHD, Pitch 2.54mm, SingleRow, 4pins | P1, P2, P3 | CMP-1502-01064-4 | Uptodate | 3 | WurthElektronik | 61300411121 | Unknown | Mouser | 710-61300411121 | 0.19 | 0.57
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

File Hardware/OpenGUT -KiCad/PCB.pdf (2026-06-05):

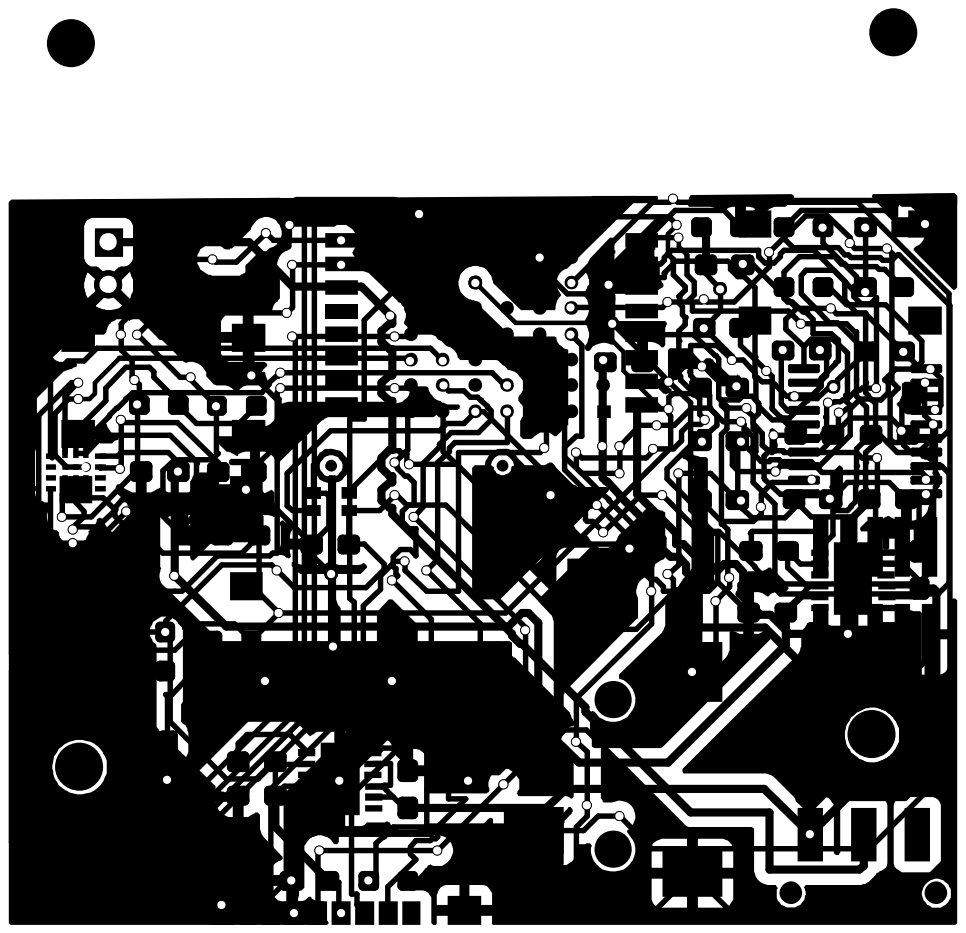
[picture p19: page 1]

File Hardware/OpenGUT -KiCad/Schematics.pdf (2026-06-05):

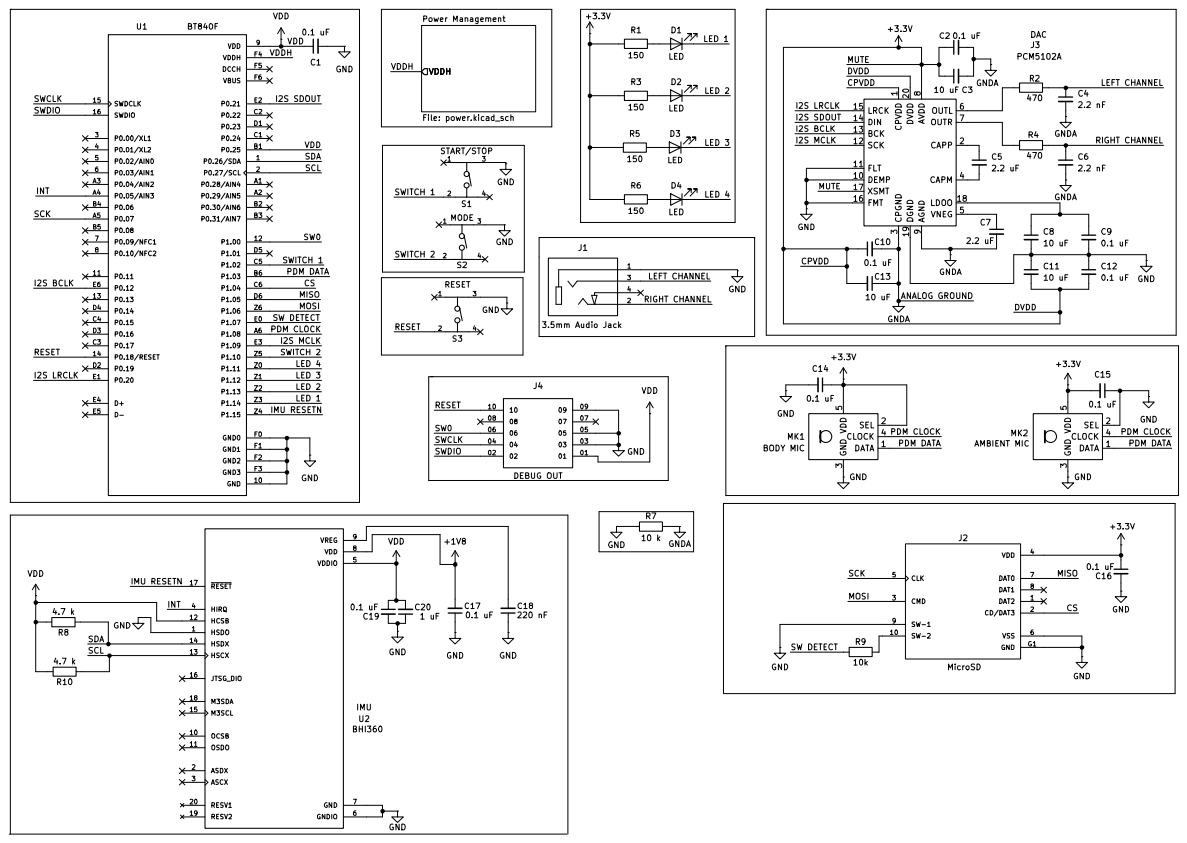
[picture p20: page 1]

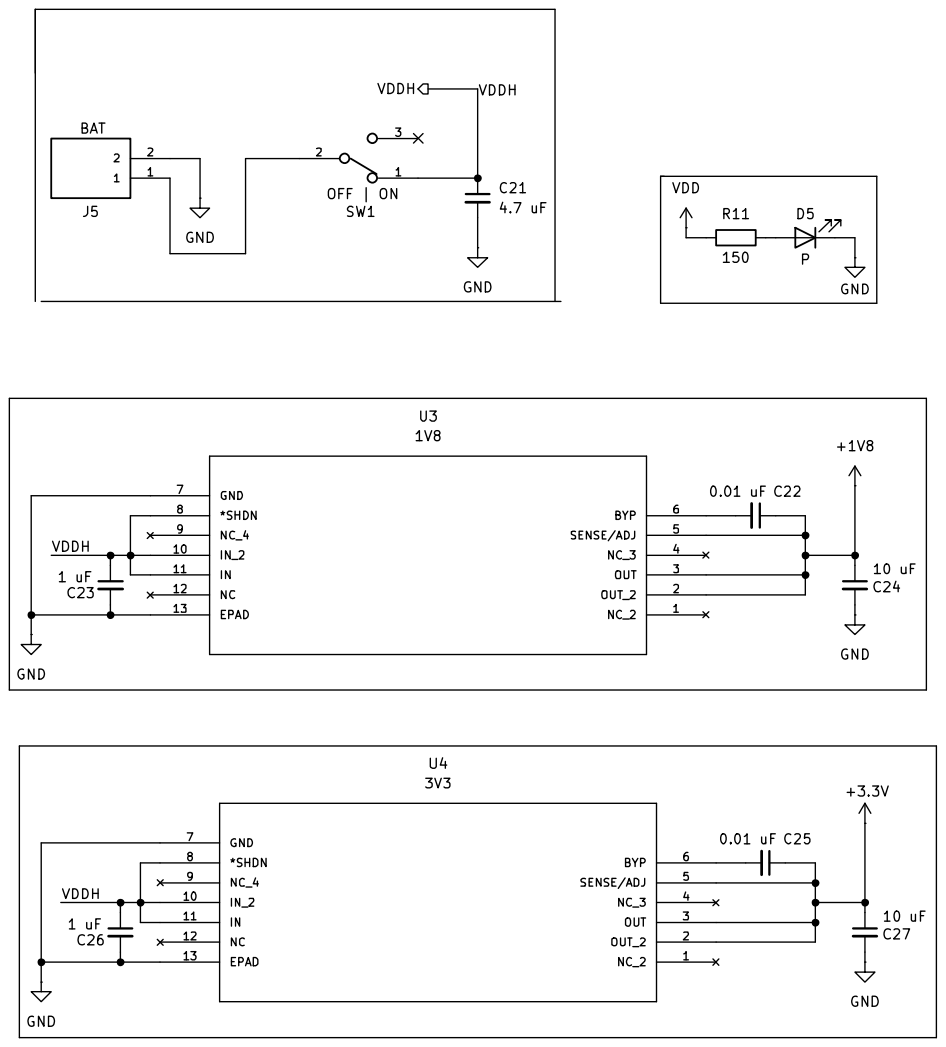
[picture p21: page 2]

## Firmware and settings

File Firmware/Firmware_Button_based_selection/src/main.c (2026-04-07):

#include <stdint.h>
#include <stdbool.h>
#include <errno.h>

#include <zephyr/kernel.h>
#include <mdk/nrf52840.h>

#include "PDM.h"
#include "Playback.h"
#include "led.h"
#include "swicthes.h"

#define STARTUP_LED_ON_MS 500U
#define ERROR_BLINK_ON_MS 150U
#define ERROR_BLINK_OFF_MS 250U
#define STATUS_BLINK_ON_MS 150U
#define STATUS_BLINK_OFF_MS 150U
#define MODE_FLASH_COUNT 3U
#define MODE_FLASH_ON_MS 150U
#define MODE_FLASH_OFF_MS 150U
#define SW1_SHORT_PRESS 1U
#define SW1_LONG_PRESS 2U
#define SW1_LONG_PRESS_MS 700U
#define SWITCH_POLL_MS 20U
#define VDD_OUTPUT_TARGET (UICR_REGOUT0_VOUT_3V0 << UICR_REGOUT0_VOUT_Pos)

typedef enum {
    MODE_RECORD_STEREO = 0,
    MODE_LIVE_MONITOR,
    MODE_PLAY_LOUD,
    MODE_PLAY_MEDIUM,
    MODE_COUNT,
} app_mode_t;

static volatile bool blink_active;
static volatile uint8_t blinking_led;
K_THREAD_STACK_DEFINE(status_blink_stack, 512);
static struct k_thread status_blink_thread;

static void nvmc_wait_ready(void)
{
    while (NRF_NVMC->READY == NVMC_READY_READY_Busy) {
    }
}

static int configure_vdd_output_3v0(void)
{
    uint32_t regout0 = NRF_UICR->REGOUT0;
    uint32_t current_vdd = regout0 & UICR_REGOUT0_VOUT_Msk;

    if (current_vdd == VDD_OUTPUT_TARGET) {
        return 0;
    }

    /*
     * UICR writes can only clear bits from 1 to 0. Moving from a lower
     * voltage code to 3.0 V would require erasing the full UICR page, which
     * we avoid here because it can affect unrelated configuration.
     */
    if ((current_vdd & VDD_OUTPUT_TARGET) != VDD_OUTPUT_TARGET) {
        return -ENOTSUP;
    }

    nvmc_wait_ready();
    NRF_NVMC->CONFIG = NVMC_CONFIG_WEN_Wen << NVMC_CONFIG_WEN_Pos;
    nvmc_wait_ready();

    NRF_UICR->REGOUT0 = (regout0 & ~UICR_REGOUT0_VOUT_Msk) | VDD_OUTPUT_TARGET;
    nvmc_wait_ready();

    NRF_NVMC->CONFIG = NVMC_CONFIG_WEN_Ren << NVMC_CONFIG_WEN_Pos;
    nvmc_wait_ready();

    NVIC_SystemReset();
    return 0;
}

static int led_set_only(uint8_t led_number, led_state_t state)
{
    for (uint8_t current_led = 1U; current_led <= 4U; ++current_led) {
        int ret = Led(current_led,
                      (current_led == led_number) ? state : stop);
        if (ret < 0) {
            return ret;
        }
    }

    return 0;
}

static int set_all_leds(led_state_t state)
{
    for (uint8_t led_number = 1U; led_number <= 4U; ++led_number) {
        int ret = Led(led_number, state);
        if (ret < 0) {
            return ret;
        }
    }

    return 0;
}

static void status_blink_thread_entry(void *arg1, void *arg2, void *arg3)
{
    ARG_UNUSED(arg1);
    ARG_UNUSED(arg2);
    ARG_UNUSED(arg3);

    while (1) {
        if (blink_active) {
            (void)led_set_only(blinking_led, start);
            k_sleep(K_MSEC(STATUS_BLINK_ON_MS));
            (void)led_set_only(blinking_led, stop);
            k_sleep(K_MSEC(STATUS_BLINK_OFF_MS));
        } else {
            k_sleep(K_MSEC(SWITCH_POLL_MS));
        }
    }
}

static void status_blink_start(uint8_t led_number)
{
    blinking_led = led_number;
    blink_active = true;
}

static int status_blink_stop_and_show_mode(uint8_t led_number)
{
    blink_active = false;

    /*
     * Let the blink thread finish any in-flight off transition before
     * leaving the completion indication latched on.
     */
    k_sleep(K_MSEC(STATUS_BLINK_OFF_MS));

    blinking_led = led_number;
    return led_set_only(led_number, start);
}

static int show_selected_mode(app_mode_t mode)
{
    blinking_led = (uint8_t)mode + 1U;
    return led_set_only(blinking_led, start);
}

static int flash_selected_mode(app_mode_t mode, uint32_t flash_count)
{
    uint8_t led_number = (uint8_t)mode + 1U;

    for (uint32_t flash = 0U; flash < flash_count; ++flash) {
        int ret = Led(led_number, start);
        if (ret < 0) {
            return ret;
        }

        k_sleep(K_MSEC(MODE_FLASH_ON_MS));

        ret = Led(led_number, stop);
        if (ret < 0) {
            return ret;
        }

        k_sleep(K_MSEC(MODE_FLASH_OFF_MS));
    }

    return show_selected_mode(mode);
}

static void wait_for_switch_release(uint8_t switch_number)
{
    while (Switch_Is_Down(switch_number)) {
        k_sleep(K_MSEC(SWITCH_POLL_MS));
    }
}

static uint8_t read_sw1_action(void)
{
    uint32_t pressed_ms = 0U;

    while (Switch_Is_Down(1U)) {
        k_sleep(K_MSEC(SWITCH_POLL_MS));
        pressed_ms += SWITCH_POLL_MS;
    }

    return (pressed_ms >= SW1_LONG_PRESS_MS) ? SW1_LONG_PRESS : SW1_SHORT_PRESS;
}

static app_mode_t next_mode(app_mode_t mode)
{
    return (app_mode_t)(((uint32_t)mode + 1U) % MODE_COUNT);
}

static app_mode_t previous_mode(app_mode_t mode)
{
    return (app_mode_t)(((uint32_t)mode + MODE_COUNT - 1U) % MODE_COUNT);
}

static bool live_monitor_stop_requested(void *context)
{
    ARG_UNUSED(context);
    return Switch_Pressed(2U);
}

static bool record_stop_requested(void *context)
{
    ARG_UNUSED(context);
    return Switch_Pressed(2U);
}

static int run_record_mode(void)
{
    int ret;

    Switches_Clear_All();
    wait_for_switch_release(2U);

    status_blink_start(1U);
    ret = PDM_Record_Stereo_Wav_Until(record_stop_requested, NULL);
    if (ret < 0) {
        return ret;
    }

    ret = status_blink_stop_and_show_mode(1U);
    if (ret < 0) {
        return ret;
    }

    return flash_selected_mode(MODE_RECORD_STEREO, MODE_FLASH_COUNT);
}

static int run_live_monitor_mode(void)
{
    int ret;

    Switches_Clear_All();
    wait_for_switch_release(2U);

    status_blink_start(2U);
    ret = PDM_Live_Monitor_Until(live_monitor_stop_requested, NULL);
    if (ret < 0) {
        return ret;
    }

    return status_blink_stop_and_show_mode(2U);
}

static int run_playback_mode(app_mode_t mode, const char *file_path)
{
    int ret;
    uint8_t led_number = (uint8_t)mode + 1U;

    Switches_Clear_All();
    wait_for_switch_release(2U);

    status_blink_start(led_number);
    ret = Playback_Play_Wav(file_path, 0U);
    if (ret < 0) {
        return ret;
    }

    ret = status_blink_stop_and_show_mode(led_number);
    if (ret < 0) {
        return ret;
    }

    return flash_selected_mode(mode, MODE_FLASH_COUNT);
}

static void fatal_error_loop(uint8_t led_number)
{
    while (1) {
        (void)Led(led_number, start);
        k_sleep(K_MSEC(ERROR_BLINK_ON_MS));
        (void)Led(led_number, stop);
        k_sleep(K_MSEC(ERROR_BLINK_OFF_MS));
    }
}

int main(void)
{
    int ret;
    app_mode_t mode = MODE_RECORD_STEREO;

    ret = configure_vdd_output_3v0();
    if (ret < 0) {
        return ret;
    }

    (void)k_thread_create(&status_blink_thread,
                          status_blink_stack,
                          K_THREAD_STACK_SIZEOF(status_blink_stack),
                          status_blink_thread_entry,
                          NULL,
                          NULL,
                          NULL,
                          K_LOWEST_APPLICATION_THREAD_PRIO,
                          0,
                          K_NO_WAIT);

    ret = set_all_leds(start);

    if (ret < 0) {
        return ret;
    }

    k_sleep(K_MSEC(STARTUP_LED_ON_MS));

    ret = set_all_leds(stop);
    if (ret < 0) {
        return ret;
    }

    ret = Switches_Init();
    if (ret < 0) {
        fatal_error_loop(1U);
    }

    Switches_Clear_All();

    while (1) {
        ret = show_selected_mode(mode);
        if (ret < 0) {
            fatal_error_loop((uint8_t)mode + 1U);
        }

        if (Switch_Pressed(2U)) {
            wait_for_switch_release(2U);

            switch (mode) {
            case MODE_RECORD_STEREO:
                ret = run_record_mode();
                break;
            case MODE_LIVE_MONITOR:
                ret = run_live_monitor_mode();
                break;
            case MODE_PLAY_LOUD:
                ret = run_playback_mode(mode, "/SD:/loud.wav");
                break;
            case MODE_PLAY_MEDIUM:
                ret = run_playback_mode(mode, "/SD:/medium.wav");
                break;
            default:
                ret = -EINVAL;
                break;
            }

            if (ret < 0) {
                fatal_error_loop((uint8_t)mode + 1U);
            }

            Switches_Clear_All();
            continue;
        }

        if (Switch_Pressed(1U)) {
            uint8_t action;

            action = read_sw1_action();
            mode = (action == SW1_LONG_PRESS) ? previous_mode(mode) : next_mode(mode);
            Switches_Clear_All();
        }

        k_sleep(K_MSEC(SWITCH_POLL_MS));
    }
}

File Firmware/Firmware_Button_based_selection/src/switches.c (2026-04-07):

#include <errno.h>
#include <stdbool.h>
#include <stddef.h>

#include <zephyr/device.h>
#include <zephyr/drivers/gpio.h>
#include <zephyr/kernel.h>
#include <zephyr/sys/atomic.h>

#include "swicthes.h"

#define SWITCH_DEBOUNCE_MS 20

static const struct gpio_dt_spec switches[] = {
    GPIO_DT_SPEC_GET(DT_ALIAS(sw0), gpios),
    GPIO_DT_SPEC_GET(DT_ALIAS(sw1), gpios),
};

static bool switches_initialized;
static struct gpio_callback switch_callbacks[ARRAY_SIZE(switches)];
static atomic_t switch_events;
static uint32_t last_press_ms[ARRAY_SIZE(switches)];

static int switch_index_from_number(uint8_t switch_number, size_t *index)
{
    if ((switch_number == 0U) || (switch_number > ARRAY_SIZE(switches))) {
        return -EINVAL;
    }

    *index = switch_number - 1U;
    return 0;
}

static void switch_pressed_isr(const struct device *port,
                               struct gpio_callback *callback,
                               gpio_port_pins_t pins)
{
    uint32_t now = k_uptime_get_32();

    for (size_t i = 0; i < ARRAY_SIZE(switches); ++i) {
        if ((switches[i].port == port) &&
            ((pins & BIT(switches[i].pin)) != 0U) &&
            (callback == &switch_callbacks[i])) {
            if ((now - last_press_ms[i]) >= SWITCH_DEBOUNCE_MS) {
                last_press_ms[i] = now;
                atomic_or(&switch_events, BIT(i));
            }
            return;
        }
    }
}

int Switches_Init(void)
{
    if (switches_initialized) {
        return 0;
    }

    for (size_t i = 0; i < ARRAY_SIZE(switches); ++i) {
        if (!gpio_is_ready_dt(&switches[i])) {
            return -ENODEV;
        }

        int ret = gpio_pin_configure_dt(&switches[i], GPIO_INPUT);
        if (ret < 0) {
            return ret;
        }

        ret = gpio_pin_interrupt_configure_dt(&switches[i],
                                              GPIO_INT_EDGE_TO_ACTIVE);
        if (ret < 0) {
            return ret;
        }

        gpio_init_callback(&switch_callbacks[i],
                           switch_pressed_isr,
                           BIT(switches[i].pin));

        ret = gpio_add_callback(switches[i].port, &switch_callbacks[i]);
        if (ret < 0) {
            return ret;
        }
    }

    switches_initialized = true;
    return 0;
}

bool Switch_Pressed(uint8_t switch_number)
{
    size_t index;
    int ret = Switches_Init();
    atomic_val_t value;

    if (ret < 0) {
        return false;
    }

    ret = switch_index_from_number(switch_number, &index);
    if (ret < 0) {
        return false;
    }

    value = atomic_and(&switch_events, ~BIT(index));
    if ((value & BIT(index)) == 0) {
        return false;
    }

    return true;
}

bool Switch_Is_Down(uint8_t switch_number)
{
    size_t index;
    int ret = Switches_Init();
    int value;

    if (ret < 0) {
        return false;
    }

    ret = switch_index_from_number(switch_number, &index);
    if (ret < 0) {
        return false;
    }

    value = gpio_pin_get_dt(&switches[index]);
    if (value < 0) {
        return false;
    }

    return value != 0;
}

void Switches_Clear_All(void)
{
    (void)atomic_set(&switch_events, 0);
}

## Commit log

2026-04-07 Add README for PCB design files
2026-04-07 Design Files
    [Bottom Cover.SLDPRT, Cone.SLDPRT, Cone.STL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]
2026-04-10 Fix include statement for switches header file
    [switches.c]
2026-04-10 Fix filename typo in switches.h
2026-04-10 Revise README for firmware options and features
    Updated the README to reflect firmware options and features, including UI-based and button-based selections.
2026-06-05 KiCad PCB Design Documents for OpenGUT
    [OpenGUT-B_Cu.gbr, OpenGUT-B_Mask.gbr, OpenGUT-B_Paste.gbr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]
2026-06-05 Add README for OpenGUT KiCad project
    Added README for OpenGUT KiCad PCB design files, highlighting contributions and repository structure.
